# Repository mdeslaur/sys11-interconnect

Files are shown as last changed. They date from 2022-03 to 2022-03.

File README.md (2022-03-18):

# Williams System 11 Interconnect board

This is a replacement interconnect board for use in Williams System 11B
pinball machines. The original part number is D-12313-x (x varies per
game).

Each game has a specific combination of resistor values, jumpers, and
populated connectors. See the manual for each game to know what the
appropriate values are, and which connectors need to be populated.

Swords of Fury and Taxi use a slightly older version of this board that
doesn't have the optocouplers at U2 and U3.

Version 1.0 of this design was tested successfully in Diner.

Change history:  
1.0 - Initial version  
1.1 - Moved some traces further away from J19  

To Do:  
- Clean up the schematic, goal was to make a PCB, not a schematic.  
- Modify Molex connector footprints to make pads longer  

Marc Deslauriers
2022-05-17

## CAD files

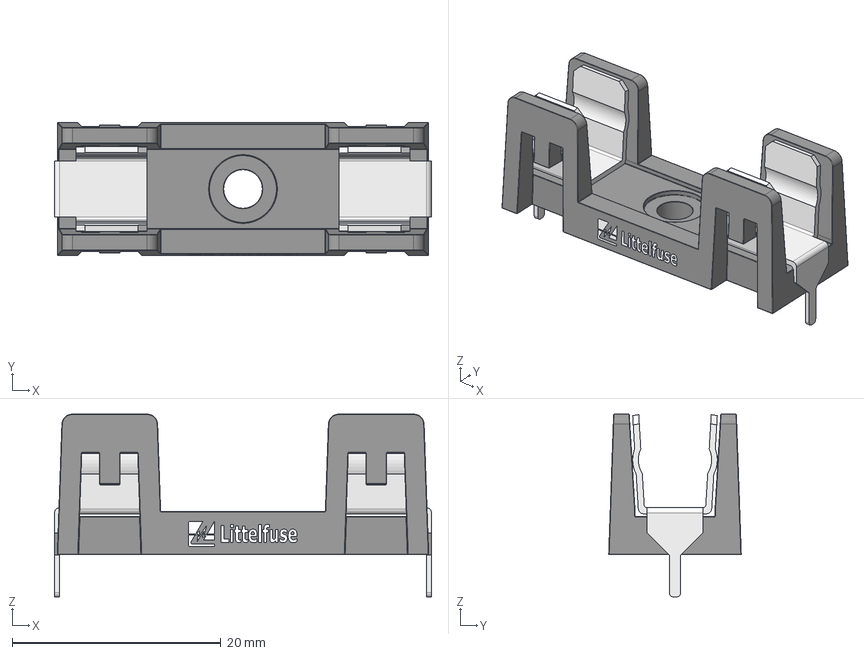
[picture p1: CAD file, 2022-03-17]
Littelfuse_Inc_-_03540101ZXGY.step
36.1 x 12.7 x 17.5 mm
base plastic
pins
logo

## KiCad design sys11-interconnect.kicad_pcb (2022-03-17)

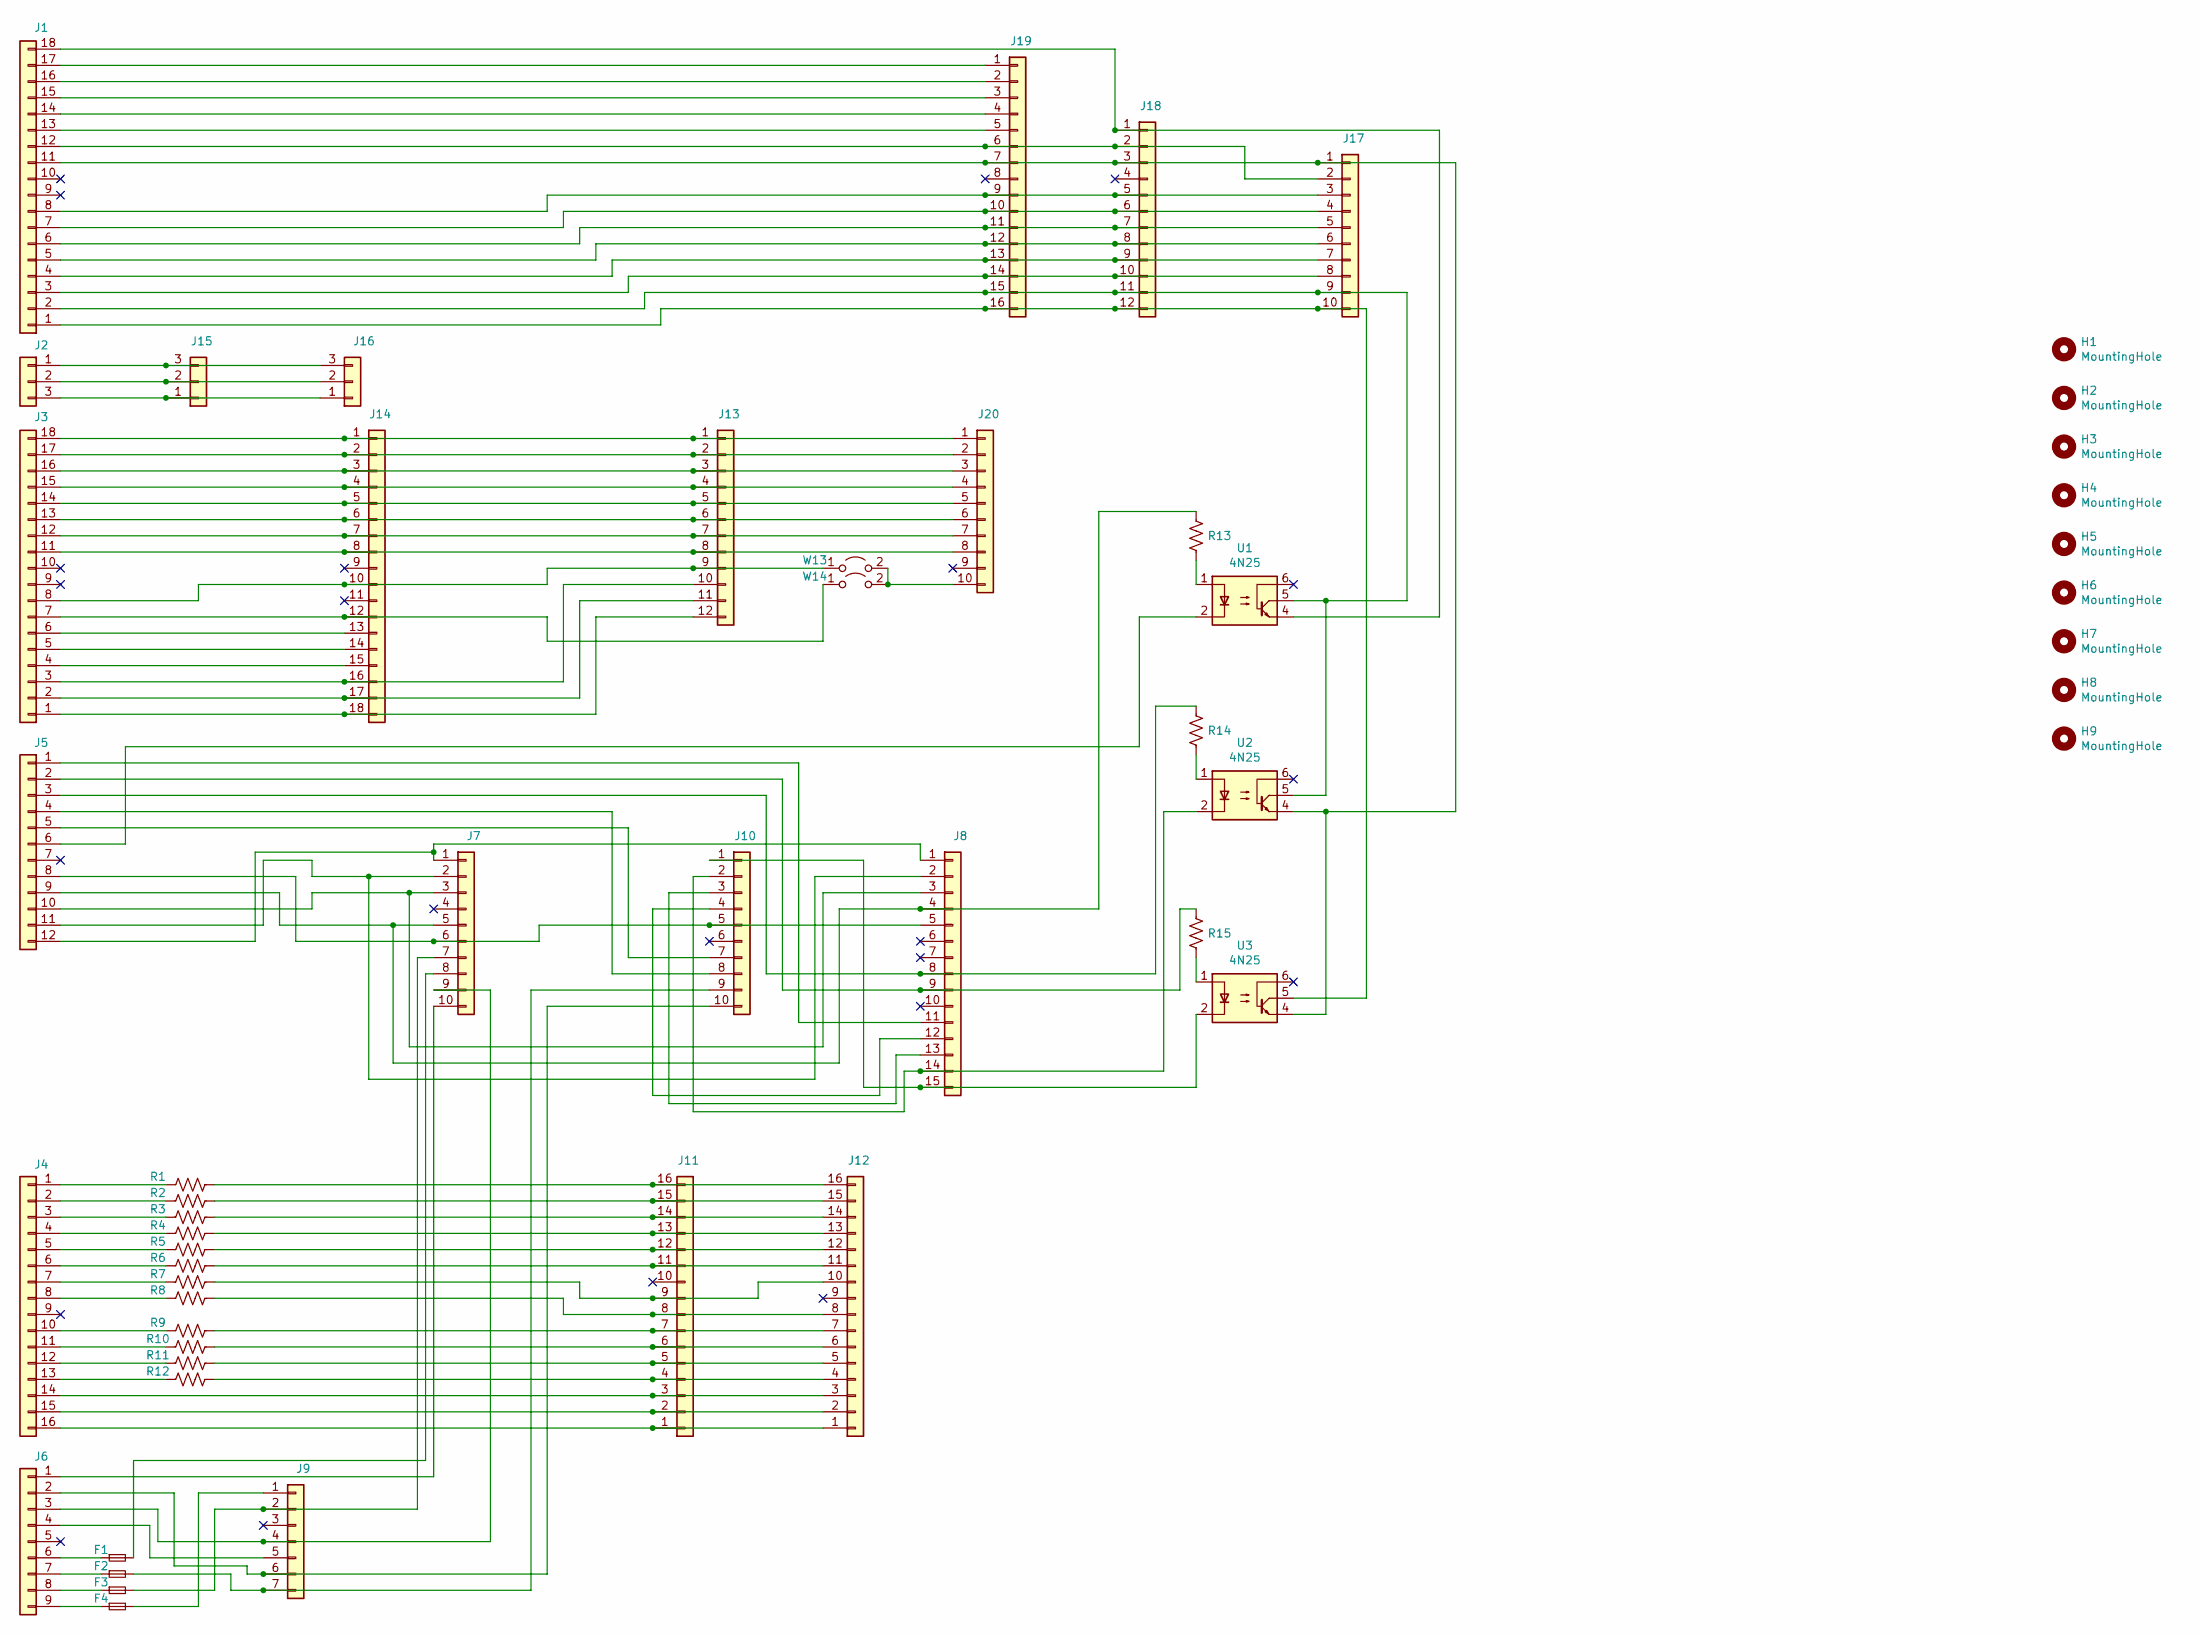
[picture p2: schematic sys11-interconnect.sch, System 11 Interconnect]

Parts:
F1, F2, F3, F4: Fuse_Small; Littelfuse_Inc-03540101ZXGY-MFG-combo
H1, H2, H3, H4, H5, H6, H7, H8, H9: MountingHole; MountingHole_4.5mm
J1, J3, J14: Conn_01x18; Molex_KK-396_A-41791-0018_1x18_P3.96mm_Vertical
J2, J15, J16: Conn_01x03; Molex_KK-396_A-41791-0003_1x03_P3.96mm_Vertical
J4, J11, J12, J19: Conn_01x16; Molex_KK-396_A-41791-0016_1x16_P3.96mm_Vertical
J5, J13, J18: Conn_01x12; Molex_KK-396_A-41791-0012_1x12_P3.96mm_Vertical
J6: Conn_01x09; Molex_KK-396_A-41791-0009_1x09_P3.96mm_Vertical
J7, J10, J17, J20: Conn_01x10; Molex_KK-396_A-41791-0010_1x10_P3.96mm_Vertical
J8: Conn_01x15; Molex_KK-396_A-41791-0015_1x15_P3.96mm_Vertical
J9: Conn_01x07; Molex_KK-396_A-41791-0007_1x07_P3.96mm_Vertical
R1, R2, R3, R4, R5, R6, R7, R8, R9, R10, R11, R12: R_US; R_Axial_DIN0922_L20.0mm_D9.0mm_P30.48mm_Horizontal-combo
R13, R14, R15: R_US; R_Axial_DIN0922_L20.0mm_D9.0mm_P30.48mm_Horizontal
U1, U2, U3: 4N25; DIP-6_W7.62mm
W13, W14: Jumper_2_Open; R_Axial_DIN0309_L9.0mm_D3.2mm_P12.70mm_Horizontal

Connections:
unnamed: F1.1, J6.6
unnamed: F1.2, J7.8
unnamed: F2.1, J6.7
unnamed: F2.2, J9.7, J10.9
unnamed: F3.1, J6.8
unnamed: F3.2, J7.7, J9.2
unnamed: F4.1, J6.9
unnamed: F4.2, J9.1
unnamed: J1.1, J17.10, J18.12, J19.16, U3.5
unnamed: J1.2, J17.9, J18.11, J19.15, U1.5, U2.5
unnamed: J1.3, J17.8, J18.10, J19.14
unnamed: J1.4, J17.7, J18.9, J19.13
unnamed: J1.5, J17.6, J18.8, J19.12
unnamed: J1.6, J17.5, J18.7, J19.11
unnamed: J1.7, J17.4, J18.6, J19.10
unnamed: J1.8, J17.3, J18.5, J19.9
unnamed: J1.11, J17.1, J18.3, J19.7, U2.4, U3.4
unnamed: J1.12, J17.2, J18.2, J19.6
unnamed: J1.13, J19.5
unnamed: J1.14, J19.4
unnamed: J1.15, J19.3
unnamed: J1.16, J19.2
unnamed: J1.17, J19.1
unnamed: J1.18, J18.1, U1.4
unnamed: J4.1, R1.2
unnamed: J4.2, R2.2
unnamed: J4.3, R3.2
unnamed: J4.4, R4.2
unnamed: J4.5, R5.2
unnamed: J4.6, R6.2
unnamed: J4.7, R7.2
unnamed: J4.8, R8.2
unnamed: J4.10, R9.2
unnamed: J4.11, R10.2
unnamed: J4.12, R11.2
unnamed: J4.13, R12.2
unnamed: J5.1, J8.11
unnamed: J5.2, J8.9, R15.1
unnamed: J5.3, J8.8, R14.1
unnamed: J5.6, U1.2
unnamed: J5.9, J7.5, J8.4, R13.1
unnamed: J5.10, J7.3, J8.3
unnamed: J5.11, J7.2, J8.2
unnamed: J5.12, J7.1, J8.1
unnamed: J6.1, J7.10
unnamed: J6.3, J7.9, J9.4
unnamed: J6.4, J9.5
unnamed: J8.15, J10.1, U3.2
unnamed: J8.14, J10.2, U2.2
unnamed: J8.13, J10.3
unnamed: J8.12, J10.4
unnamed: J5.8, J7.6, J8.5, J10.5
unnamed: J5.5, J10.7
unnamed: J5.4, J10.8
unnamed: J6.2, J9.6, J10.10
unnamed: J4.16, J11.1, J12.1
unnamed: J4.15, J11.2, J12.2
unnamed: J4.14, J11.3, J12.3
unnamed: J11.4, J12.4, R12.1
unnamed: J11.5, J12.5, R11.1
unnamed: J11.6, J12.6, R10.1
unnamed: J11.7, J12.7, R9.1
unnamed: J11.8, J12.8, R8.1
unnamed: J11.9, J12.10, R7.1
unnamed: J11.11, J12.11, R6.1
unnamed: J11.12, J12.12, R5.1
unnamed: J11.13, J12.13, R4.1
unnamed: J11.14, J12.14, R3.1
unnamed: J11.15, J12.15, R2.1
unnamed: J11.16, J12.16, R1.1
unnamed: J3.18, J13.1, J14.1, J20.1
unnamed: J3.17, J13.2, J14.2, J20.2
unnamed: J3.16, J13.3, J14.3, J20.3
unnamed: J3.15, J13.4, J14.4, J20.4
unnamed: J3.14, J13.5, J14.5, J20.5
unnamed: J3.13, J13.6, J14.6, J20.6
unnamed: J3.12, J13.7, J14.7, J20.7
unnamed: J3.11, J13.8, J14.8, J20.8
unnamed: J3.8, J13.9, J14.10, W13.1 (A)
unnamed: J3.3, J13.10, J14.16
unnamed: J3.2, J13.11, J14.17
unnamed: J3.1, J13.12, J14.18
unnamed: J3.7, J14.12, W14.1 (A)
unnamed: J3.6, J14.13
unnamed: J3.5, J14.14
unnamed: J3.4, J14.15
unnamed: J2.3, J15.1, J16.1
unnamed: J2.2, J15.2, J16.2
unnamed: J2.1, J15.3, J16.3
unnamed: J20.10, W13.2 (B), W14.2 (B)
unnamed: R13.2, U1.1
unnamed: R14.2, U2.1
unnamed: R15.2, U3.1

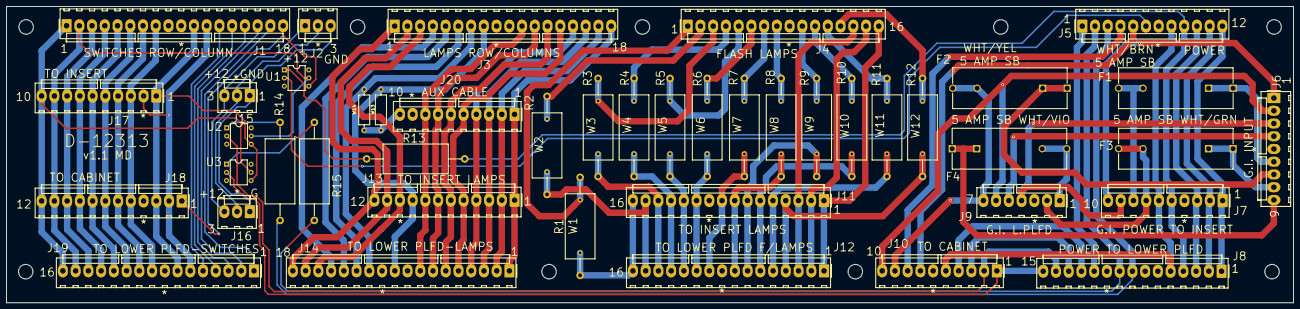
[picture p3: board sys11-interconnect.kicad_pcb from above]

Board: 2 copper layers, 400.1 x 92.1 mm, 53 parts (0 on the bottom side), 93 nets.
